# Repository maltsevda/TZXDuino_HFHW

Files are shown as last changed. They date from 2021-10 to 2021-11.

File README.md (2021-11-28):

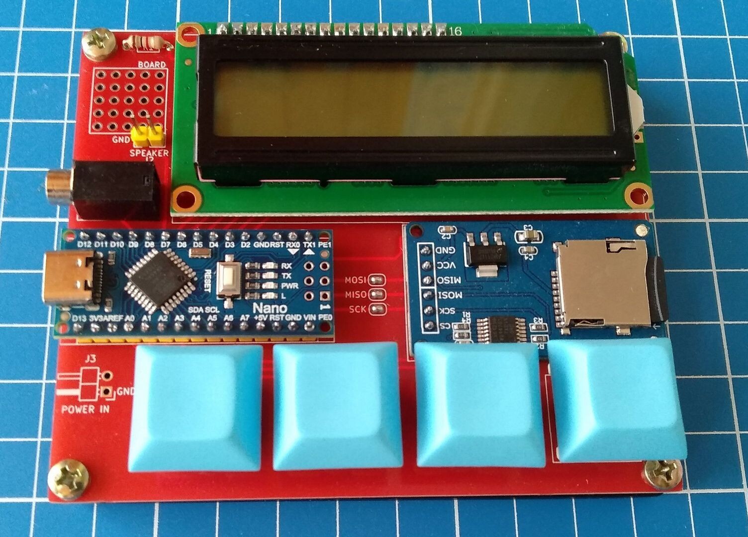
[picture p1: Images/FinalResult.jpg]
Final Result


# Описание

Это *железная* часть проекта [TZXDuino_HF](https://github.com/maltsevda/TZXDuino_HF). Для работы с проектом, требуется программа [KiCad](https://www.kicad.org/). Если нет желания с ней возиться, то в Release'ах есть готовые gerber файлы. Они точно подходят для JLCPCB, но скорее всего подойдут и для других производителей плат.

Чуть подробнее о проекте написано в [статье на habr.com](https://habr.com/ru/post/590403/).

# Необходимые компоненты

### • Arduino Nano ver. 3.0

Я рекомендую поискать вариант с USB Type-C разъемом. На будущее. Например, подойдет [такой вариант с Aliexpress](https://aliexpress.ru/item/32788387125.html).

### • LCD 1602

Подойдет любой вариант без I2C модуля. Искать в магазине по ключевым словам: `LCD 1602`. Варианты без русской локализации стоят дешево, поэтому советую их. Я использовал [такой модуль](https://aliexpress.ru/item/32500978679.html).

### • Micro SD Card Reader

Настоящее название этого модуля: `Micro SD TF Card Memory Shield Module` и оригинал можно купить [тут](https://electropeak.com/micro-sd-tf-card-adapter-module). Перед покупкой убедитесь, что распиновка совпадает с платой. Свой модуль я покупал [на Алике](https://aliexpress.ru/item/32523546123.html).

### • Кнопки

Подойдут любые кнопки для механической клавиатуры. Например, Cherry MX или их клоны. И, конечно, keycaps'ы для них. Тут советовать не буду, у каждого свои предпочтения. Нужно 4 штуки.

### • Разъем 3.5mm Headphone Jack

Я крайне рекомендую брать [разъемы у этого продавца](https://aliexpress.ru/item/32819338639.html), потому что размеры на плате подогнаны именно под них. Если будете покупать другой вариант, возможно, придется немного модифицировать плату.

### • Резистор

Нужен один резистор для настройки контрастности дисплея. Его номинал зависит от дисплея, в моем случае - это 1 кОм. Подобрать номинал можно при помощи подстроечного резистора.

### • Гребенки

Как минимум 2 гребенки по 40 контактов. Но лучше взять с запасом. Искать в магазине по ключевым словам: `40 pin single row`. Я покупал [желтый вариант](https://aliexpress.ru/item/33012665900.html).

# Советы по сборке и пайке

Перед пайкой я рекомендую проверить загрузчик на Arduino Nano и, если стоит старый `Old Bootloader`, то обновить его. В последствии его обновить можно будет только разомкнув перемычки MISO, MOSI и SCK.

Припоем замыкаем перемычки MOSI, MISO и SCK.

У гребенок на Arduino Nano и LCD 1602 пластиковую часть снимать не надо. А вот модуль SD-карты должен плотно прилегать к плате, поэтому пластиковую часть надо аккуратно снять.

Если у ваших кнопок нет направляющих (маленьких пластиковых штырьков по бокам от основной пимпочки), то уплотнить и выровнять кнопки можно при помощи небольших кусочков изоленты.

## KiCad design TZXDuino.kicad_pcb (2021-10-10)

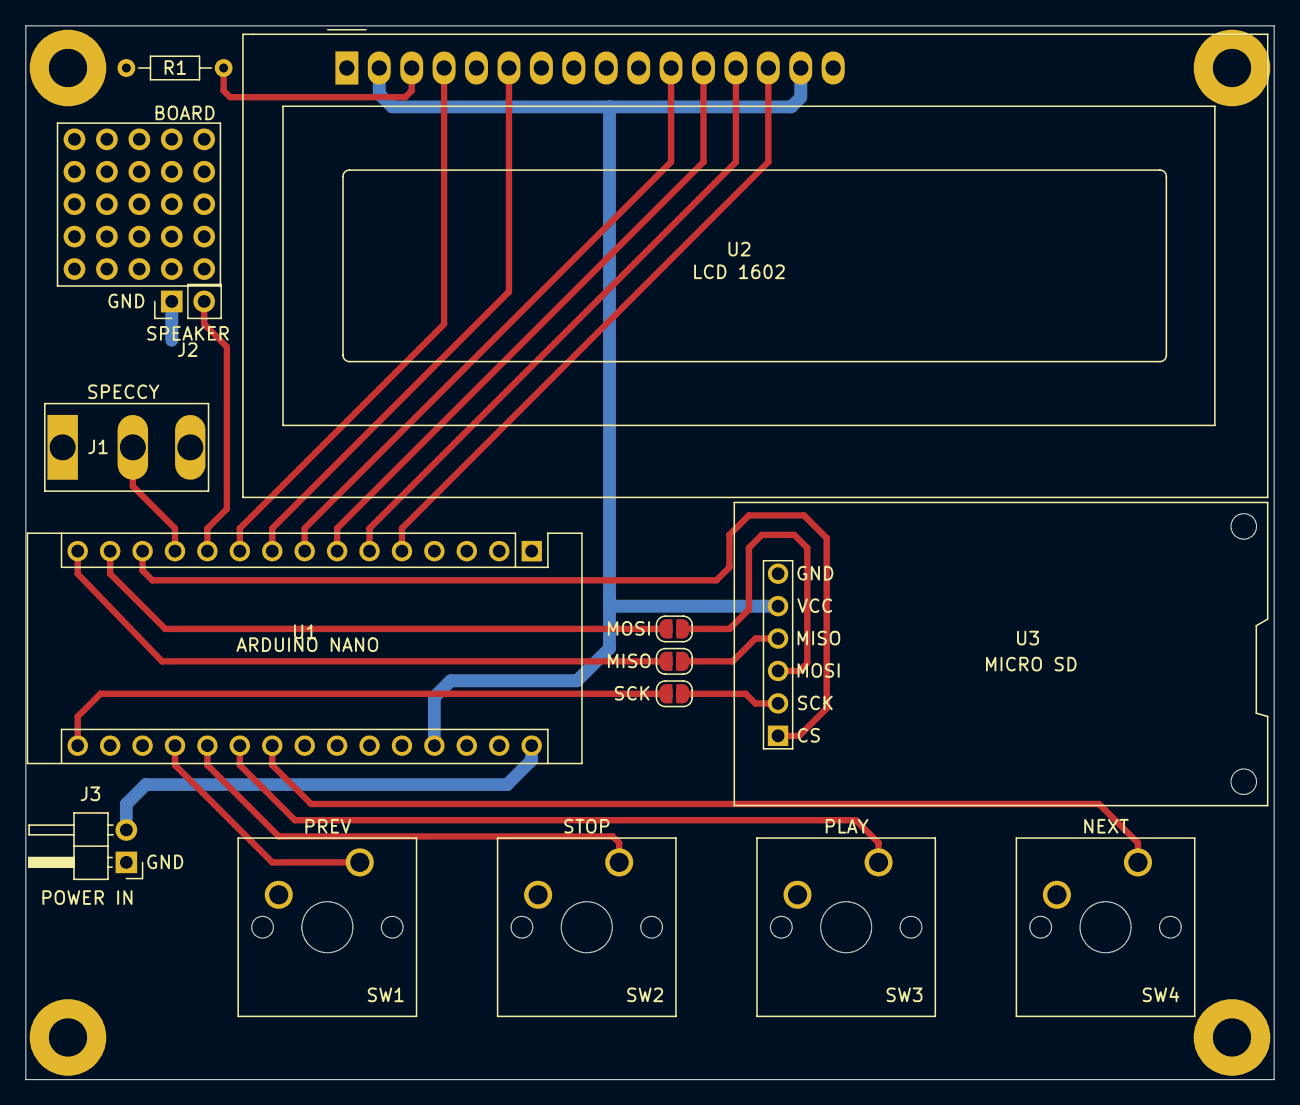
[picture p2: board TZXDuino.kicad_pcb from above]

Board: 2 copper layers, 97.8 x 82.5 mm, 19 parts (0 on the bottom side), 20 nets.

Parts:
BOARD: PROTOBOARD; ProtoBoard
H1, H2, H3, H4: MountingHole; MountingHole_3mm_Pad
J1: SPECCY; PJ-316
J2: SPEAKER; PinHeader_1x02_P2.54mm_Vertical
J3: POWER IN; PinHeader_1x02_P2.54mm_Horizontal
MISO: SolderJumper-2_P1.3mm_Open_RoundedPad1.0x1.5mm
MOSI: SolderJumper-2_P1.3mm_Open_RoundedPad1.0x1.5mm
R1: 1K; R_Axial_DIN0204_L3.6mm_D1.6mm_P7.62mm_Horizontal
SCK: SolderJumper-2_P1.3mm_Open_RoundedPad1.0x1.5mm
SW1, SW2, SW3, SW4: CHERRY MX; SW_Cherry_MX_1.00u_PCB
U1: ARDUINO NANO; Arduino_Nano
U2: LCD 1602; LCD1602
U3: Catalex_Micro_SD

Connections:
+5V: U1.27, U2.2, U2.15, U3.5
A0: SW1.1, U1.19
A1: SW2.1, U1.20
A2: SW3.1, U1.21
A3: SW4.1, U1.22
CS: U1.13, U3.1
D2: U1.5, U2.14
D3: U1.6, U2.13
D4: U1.7, U2.12
D5: U1.8, U2.11
D6: U1.9, U2.6
D7: U1.10, U2.4
D8: J2.2, U1.11
D9: J1.T, U1.12
GND: J1.S, J2.1, J3.1, R1.2, SW1.2, SW2.2, SW3.2, SW4.2, U1.4, U1.29, U2.1, U2.5, U2.16, U3.6
MISO: MISO.1, MISO.2, U1.15, U3.4
MOSI: MOSI.1, MOSI.2, U1.14, U3.3
unnamed: J3.2, U1.30
unnamed: R1.1, U2.3
SCK: SCK.1, SCK.2, U1.16, U3.2
